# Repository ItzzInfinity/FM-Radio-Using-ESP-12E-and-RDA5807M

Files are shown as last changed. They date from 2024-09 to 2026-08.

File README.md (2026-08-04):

# FM Radio — RDA5807M 📻





## 📋 Overview

A small FM receiver built around the RDA5807M, driven over I2C by either an
ESP32-C3 SuperMini or an ESP-12E — the carrier board has a footprint for both
and the firmware picks its pin map from whichever core you compile for.

Audio leaves the board on a 2-pin header to a PAM8403 amplifier and a speaker;
a telescopic antenna solders to a plated mounting hole. Beyond the original
button-cycles-presets behaviour, the current firmware brings up Wi-Fi and serves
a web UI at `http://radio.local` for presets, volume, seek and manual tuning,
supports OTA reflashing, and optionally drives an SSD1306/SH1106 OLED.

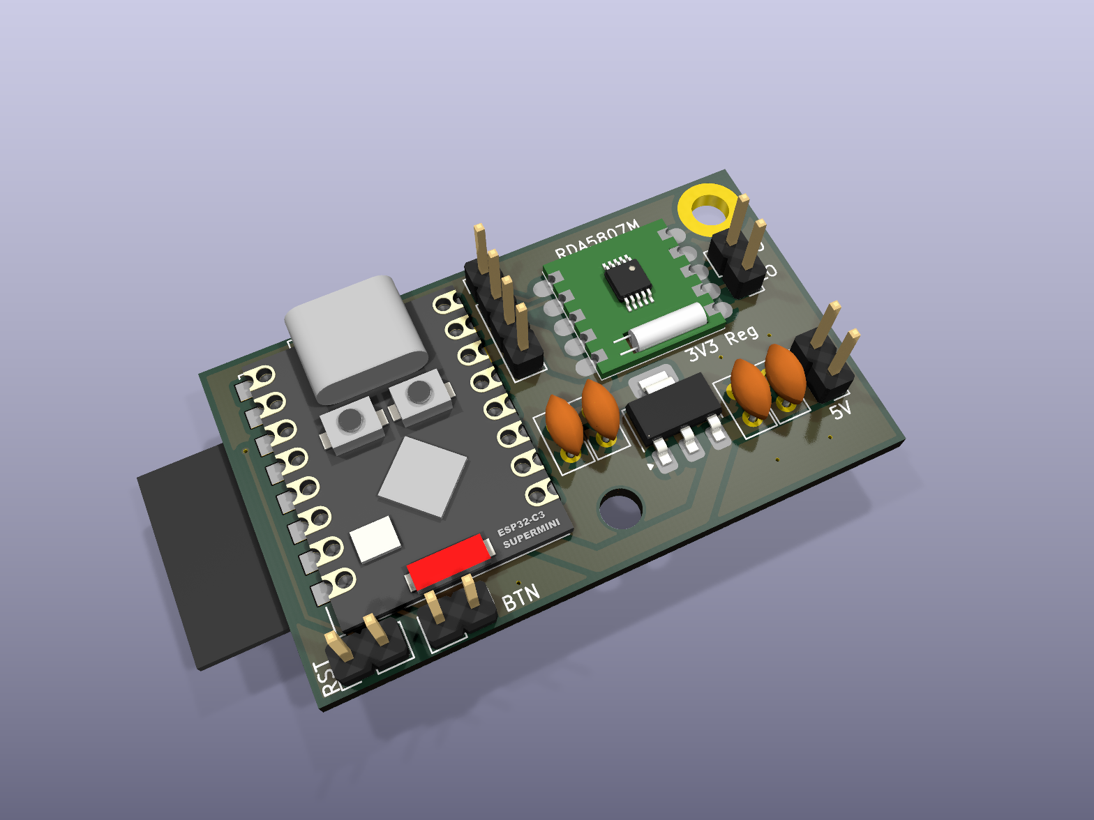
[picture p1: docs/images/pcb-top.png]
Assembled board, top view


## 🔧 Hardware

The board is a 2-layer 47.4 × 28.2 mm carrier. Reference designators differ
between the schematic and the PCB silkscreen — both are listed below.

| Sch | Silkscreen | Part | Notes |
|-----|---|---|---|
| U1 | `ESP32C3 SuperMini` | ESP32-C3 SuperMini | Top side, through-hole module |
| U2 | `ESP12E` | ESP-12E | **Bottom** side — the alternate MCU, see below |
| U3 | `U3` | RDA5807M module (RRD-102/120 style) | I2C 0x10 (sequential) / 0x11 (indexed) |
| U4 | `3V3 Reg` | AMS1117-3.3, SOT-223 | Only needed for the ESP-12E build |
| C1, C2 | `C1`, `C2` | Ceramic disc, 5 mm THT | AMS1117 input side |
| C3, C4 | `C3`, `C4` | Ceramic disc, 5 mm THT | AMS1117 output side |
| J2 | `GND` | 1×4 header | I2C breakout: SDA, SCL, 3V3, GND — for the OLED |
| J3 | `5V` | 1×2 header | 5 V supply in |
| J4 | `LO` | 1×2 header | Audio out: LOUT, ROUT → PAM8403 |
| SW1 | `RST` | 1×2 header | Reset, broken out for an external button |
| SW2 | `BTN` | 1×2 header | Preset button, broken out for an external button |
| H1 | `H1` | M3 mounting hole | |
| H2 | `H2` | M3 plated mounting hole | Carries the **ANT** net — solder the antenna here |

Notes on the BOM:

- **The capacitor values are not set in the schematic.** C1–C4 are drawn as
  generic `C` with 5 mm disc footprints. Fill them in before ordering; the
  AMS1117 datasheet wants at least 10 µF on the output for stability, which a
  disc ceramic will not give you.
- **SW1/SW2 are drawn as push buttons but laid out as 2-pin headers**, so the
  buttons live off-board. The tactile switches visible on the render are the
  SuperMini module's own boot/reset buttons, not board parts.
- H3 and H4 exist in the schematic but were never placed on the PCB.
- The PAM8403 amplifier, speaker, Li-Ion cell and TP4056 charger are off-board
  and not in this project.

### 📐 Schematic

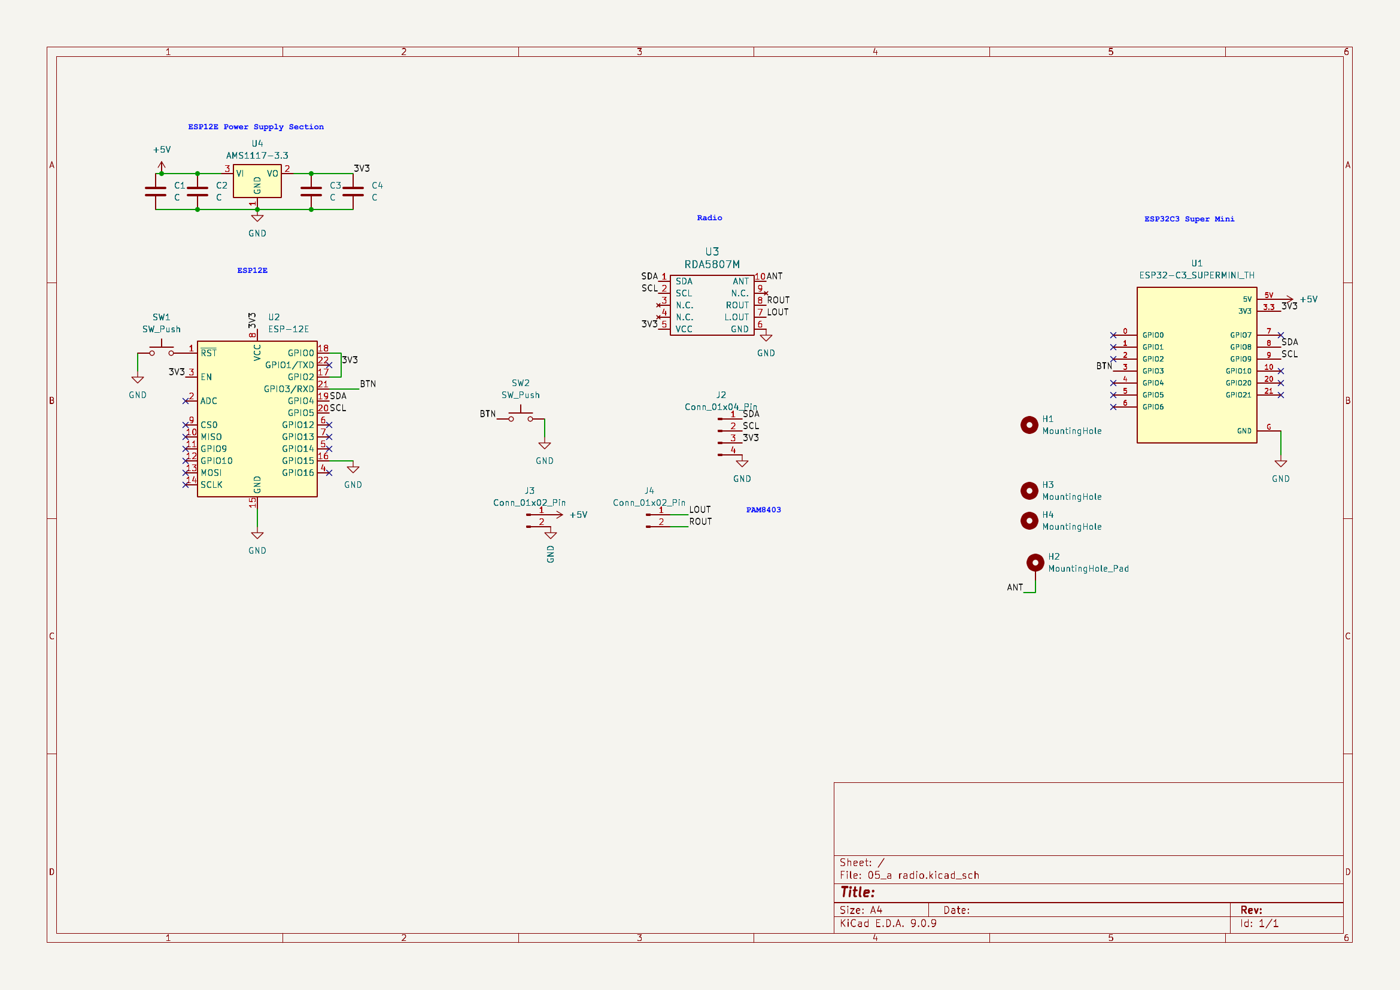
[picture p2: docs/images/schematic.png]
Schematic


*Click for the full-resolution PDF.*

### Board

| Top | Bottom |
|-----|---|
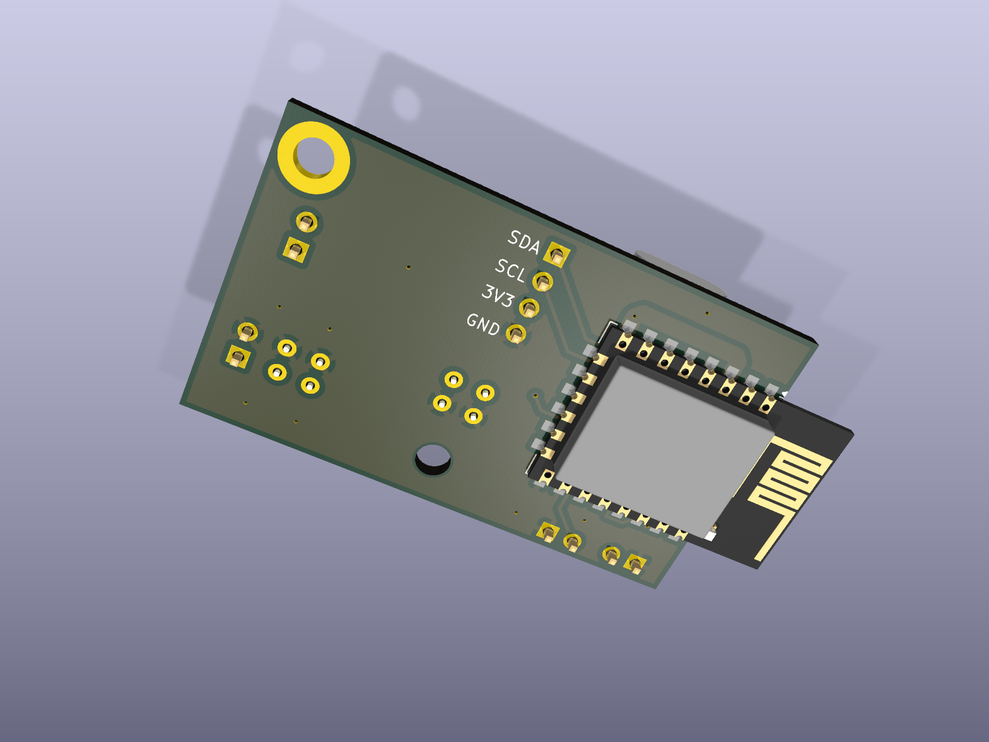
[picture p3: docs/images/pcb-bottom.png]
Bottom
| Top |  |

The KiCad 9 project is in [`hardware/`](hardware/). Both custom 3D models
(`ESP32-C3 supermini v5.step`, `RDA5807m-RRD-120.step`) are committed and
referenced through `${KIPRJMOD}`, so a fresh clone renders identically:

```bash
mkdir -p docs/images

kicad-cli sch export pdf -o docs/images/schematic.pdf "hardware/05_a radio.kicad_sch"
pdftoppm -r 200 -png -singlefile docs/images/schematic.pdf docs/images/schematic

kicad-cli pcb render --side top --quality high --perspective \
  --rotate '-25,0,25' --zoom 0.7 --width 1600 --height 1200 --floor \
  --background opaque -o docs/images/pcb-top.png "hardware/05_a radio.kicad_pcb"

kicad-cli pcb render --side bottom --quality high --perspective \
  --rotate '25,0,25' --zoom 0.52 --width 1600 --height 1200 --floor \
  --background opaque -o docs/images/pcb-bottom.png "hardware/05_a radio.kicad_pcb"
```

Gerbers are **not** committed — the exports under `hardware/Drill/` predated the
current layout, so they are gitignored. Regenerate with
`kicad-cli pcb export gerbers` before ordering.

## ⚡ Wiring

| Signal | ESP32-C3 (U1) | ESP-12E (U2) | Goes to |
|---|---|---|---|
| SDA | GPIO8 | GPIO4 (D2) | RDA5807M + J2 (OLED) |
| SCL | GPIO9 | GPIO5 (D1) | RDA5807M + J2 (OLED) |
| Button | GPIO3 | GPIO3 (RXD) | `BTN` header → GND |
| Reset | — | RST | `RST` header → GND |

These are the same values the firmware compiles in; the pin map lives in
section 2 of the sketch, keyed off `ESP8266` / `ARDUINO_ARCH_ESP32`.

### Three things that will bite you

**Populate one MCU, not both.** The ESP-12E sits on the bottom copper and the
SuperMini on the top, so nothing physically stops you fitting both — but they
share the I2C bus and the 3V3 rail. Pick one.

**Two regulators land on the same 3V3 net.** U1's `3.3` pin and the AMS1117's
output are the same node. With the SuperMini fitted, its onboard LDO already
powers the rail from the 5 V input, so leave `3V3 Reg` (U4) and C3/C4
unpopulated. The AMS1117 is only there for the ESP-12E build.

**GPIO8 and GPIO9 are ESP32-C3 strapping pins.** They are also the I2C bus here.
The chip samples both at reset — GPIO9 low selects download mode, and GPIO8 must
not be low — so the bus pull-ups have to be strong enough that nothing on the
bus drags either line down during boot. If the board only enumerates as a serial
port and never runs, this is the first thing to check.

On the ESP-12E, `pinMode()` on GPIO3 detaches it from UART0 RX: serial *output*
keeps working, serial *input* does not. That is inherited from the original
board and left as-is.

## 🧠 Design notes

**No radio library.** The RDA5807M driver is ~180 lines in section 4 of the
sketch. The chip is simple enough — 16-bit big-endian registers, two I2C
addresses (0x10 auto-incrementing, 0x11 indexed) — that a dependency buys
nothing and costs portability across the two cores.

**One sketch, two targets, no manual switch.** Everything board-specific is
behind `#if defined(ESP8266)` / `#elif defined(ARDUINO_ARCH_ESP32)`: pin map,
network headers, the web server type, and the persistence backend (EEPROM on
the ESP8266, `Preferences` on the ESP32). Selecting the board in the IDE is the
only choice you make.

**The OLED type is a runtime setting, not a compile-time one.** SSD1306 and
SH1106 are indistinguishable over I2C, so the firmware auto-detects that *an*
OLED is present and lets you switch the controller from the web page. Getting
the wrong module in a batch costs a click instead of a reflash. `OLED_ENABLED 0`
compiles the whole display path out.

**Audio survives an OTA update.** The RDA5807M only needs the MCU to change
station — it keeps playing on its own while flash is being rewritten. Both OTA
paths (the Arduino IDE network port and the browser upload at `/update`) are
guarded by `OTA_PASSWORD`, because otherwise anyone on the LAN can replace the
firmware. A failed transfer rolls back to the old image; only a successfully
written but broken sketch means opening the box.

**Credentials are gitignored.** This repo is public, so Wi-Fi and OTA passwords
live in `secrets.h`, which is not tracked. `secrets.h.example` is the template.

### HTTP API

The web page is served from flash at `/` and drives these endpoints:

| Endpoint | Purpose |
|---|---|
| `GET /api/status` | Current frequency, volume, stereo/RSSI, preset list |
| `GET /api/preset` | Select a preset slot |
| `GET /api/tune` | Tune to a frequency |
| `GET /api/volume` | Set volume 0–15 |
| `GET /api/seek` | Hardware seek up/down |
| `GET /api/preset/set` | Rewrite a preset slot (persisted) |
| `GET /api/oled` | Switch controller: `ssd1306` / `sh1106` / `none` |
| `GET`/`POST /update` | Browser firmware upload |

## 🔨 Build

```bash
cp Src/test_I2C_Radio/secrets.h.example Src/test_I2C_Radio/secrets.h
$EDITOR Src/test_I2C_Radio/secrets.h

# ESP32-C3 SuperMini
arduino-cli compile --fqbn esp32:esp32:esp32c3 Src/test_I2C_Radio

# ESP-12E
arduino-cli compile --fqbn esp8266:esp8266:nodemcuv2 Src/test_I2C_Radio
```

Requires the `Adafruit SSD1306`, `Adafruit SH110X`, `Adafruit GFX` and
`Adafruit BusIO` libraries unless you set `OLED_ENABLED 0`.

Verified with arduino-cli 1.5.1, esp32 core 3.3.8, esp8266 core 3.1.2:

| Target | Flash | RAM |
|---|---|-----|
| ESP32-C3 | 1,130,767 / 1,310,720 B (86%) | 44,252 / 327,680 B (13%) |
| ESP-12E | 340,684 / 1,048,576 B (32%) | 31,864 / 80,192 B (39%) |

Two figures worth watching: the ESP32-C3 build is at **86% of the default
1.3 MB app partition**, and the ESP-12E build sits at **93% of IRAM**
(61,551 / 65,536 B). Neither has much headroom left for new features.

## 🚀 First run

1. Copy `secrets.h.example` → `secrets.h` and fill in your Wi-Fi credentials
   and an OTA password.
2. Flash over USB the first time — OTA needs working firmware to update from.
3. Solder a telescopic antenna to the plated mounting hole H2.
4. Wire the `LO` header to a PAM8403 input and feed 5 V into the `5V` header.
   Take the amplifier's ground from that same header — `LO` carries only LOUT
   and ROUT, no ground of its own.
5. Browse to `http://radio.local`. If mDNS does not resolve, check the serial
   log for the DHCP address.
6. With no Wi-Fi at all the board still works: the `BTN` header cycles presets.

## 📟 Original prototype

The first version of this project was a hand-soldered perfboard build on an
ESP-12E with a fixed volume and 10 hard-coded stations — no Wi-Fi, no display,
one button. The carrier board above replaces it.

| Breadboard wiring | Perfboard build |
|---|---|
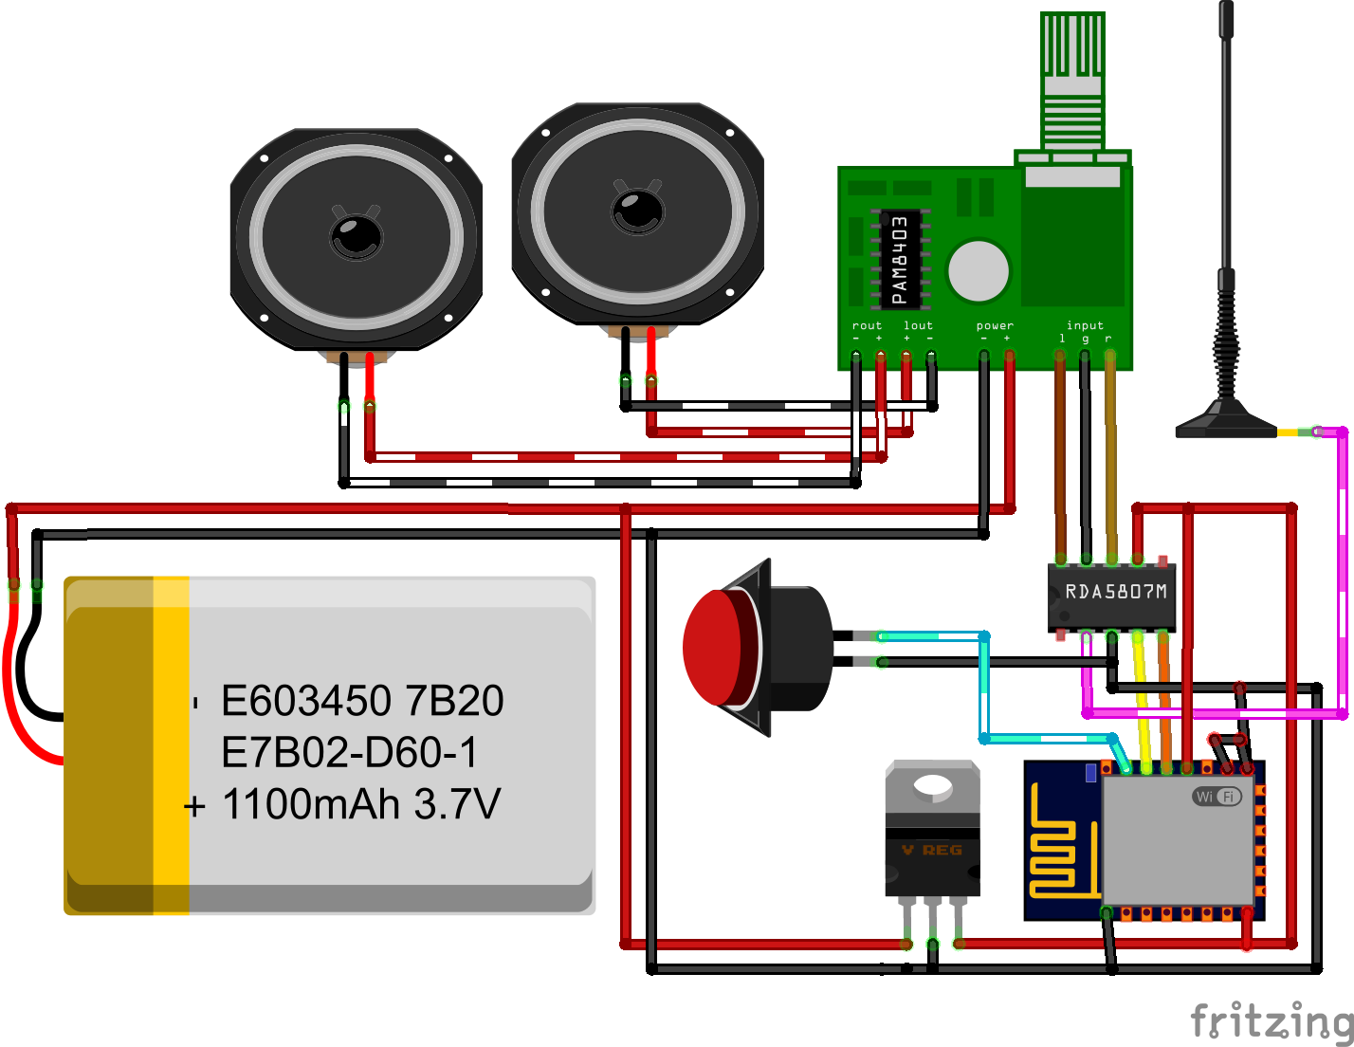
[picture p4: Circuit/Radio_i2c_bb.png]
Breadboard wiring
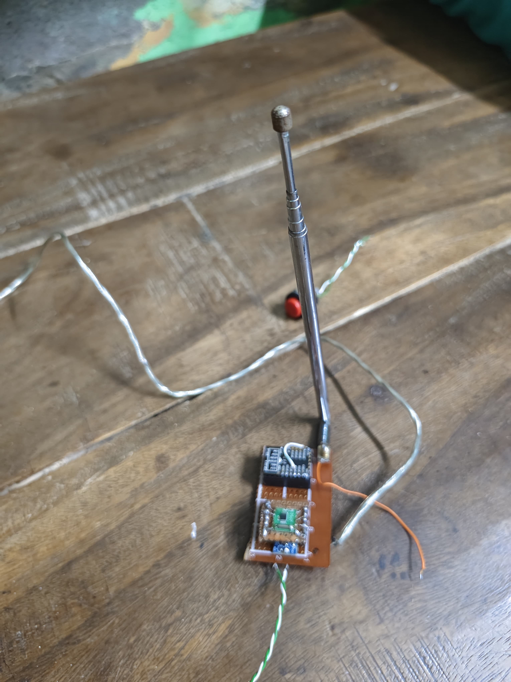
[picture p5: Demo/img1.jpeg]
Perfboard prototype
|  |  |

## 📜 License

MIT — see [LICENSE](LICENSE).

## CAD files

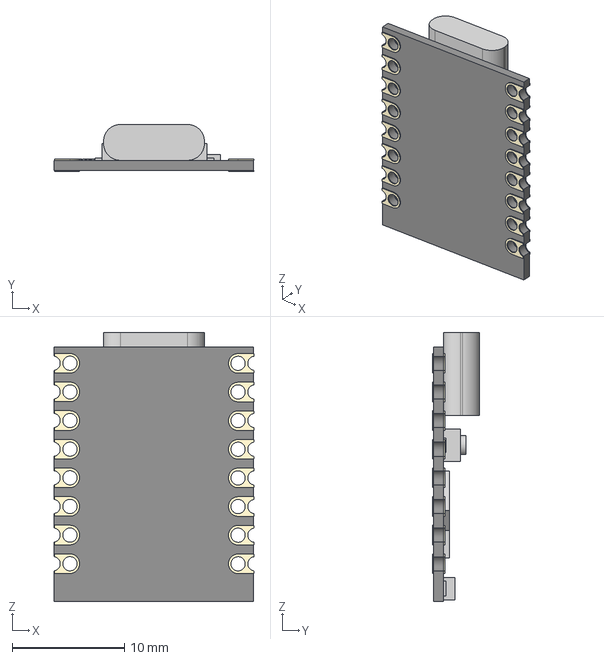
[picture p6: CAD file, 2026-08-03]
hardware/ESP32-C3 supermini v5.step
17.8 x 4.20 x 24.0 mm

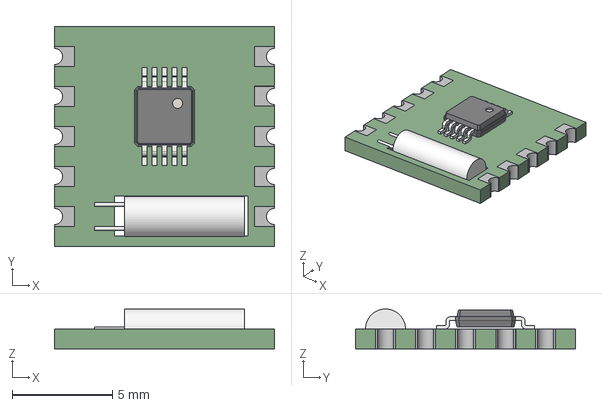
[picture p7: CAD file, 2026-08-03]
hardware/RDA5807m-RRD-120.step
11.0 x 11.0 x 2.00 mm

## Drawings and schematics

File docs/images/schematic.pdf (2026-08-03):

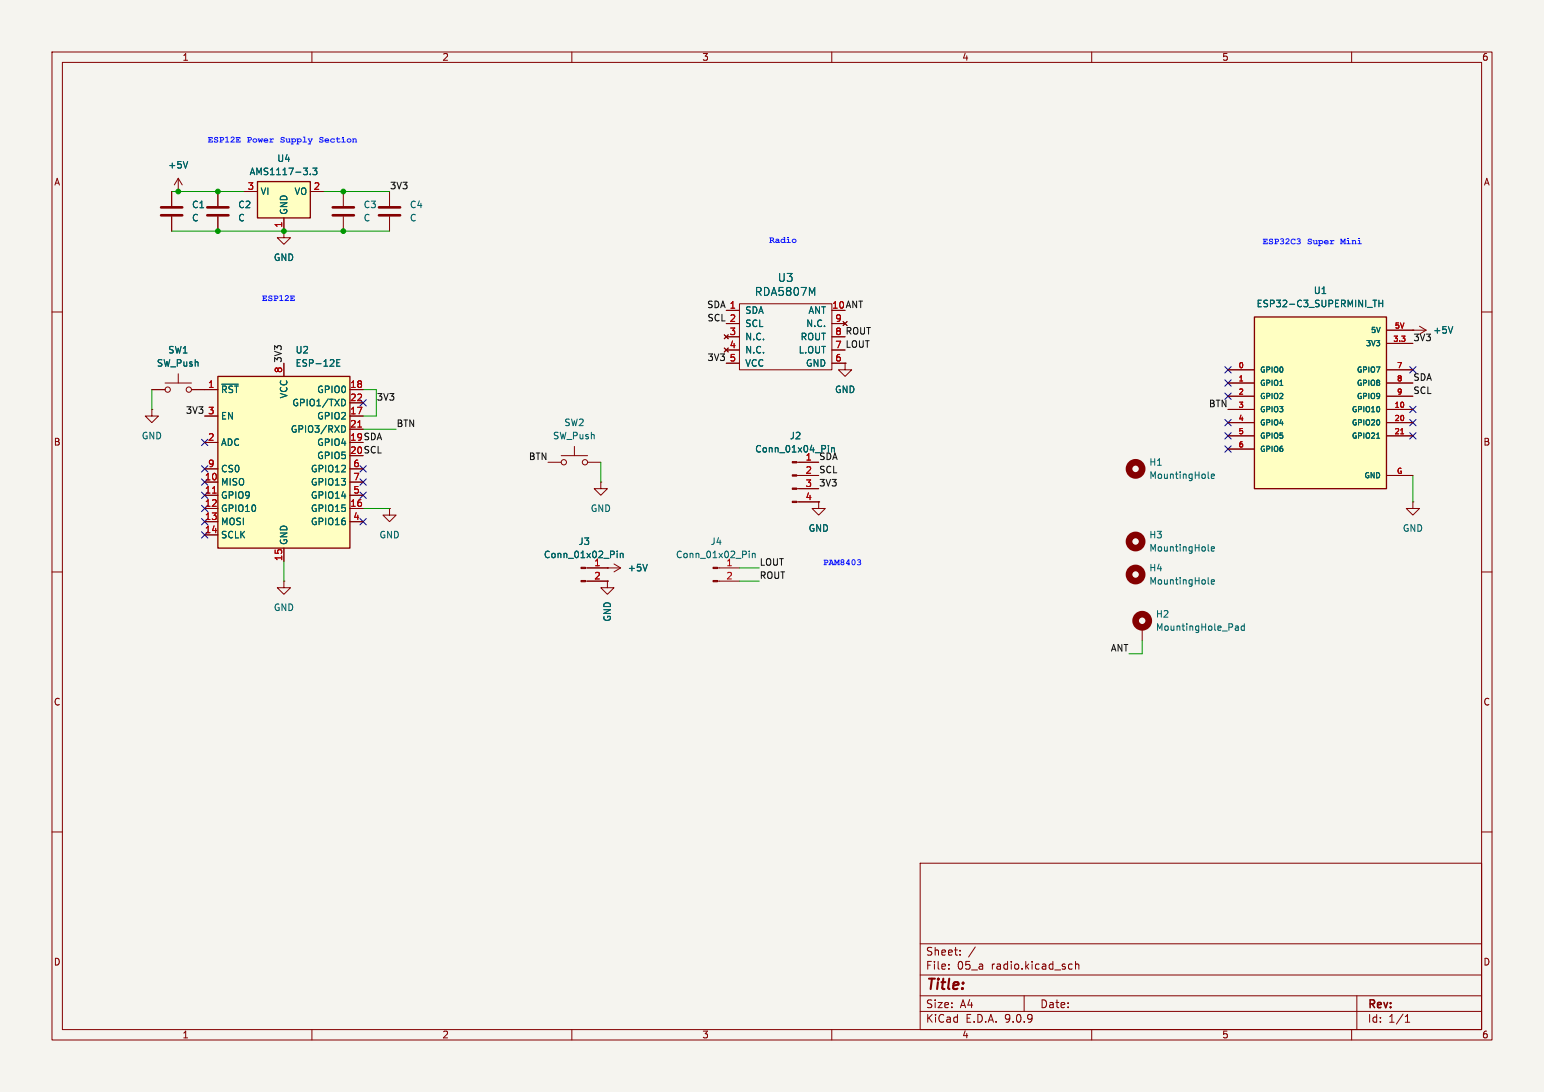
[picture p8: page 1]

8 GND 15 GPIO0 18 GPIO1/TXD 22 GPIO2 17 GPIO3/RXD 21 GPIO4 19 GPIO5 20 GPIO12 6 GPIO13 7 GPIO14 5 GPIO15 16 GPIO16 4 U2ESP-12E H4 MountingHole H3 MountingHole H2 MountingHole_Pad H1 MountingHole GND

Id: 1/1 Title: File: 05_a radio.kicad_sch Sheet: /

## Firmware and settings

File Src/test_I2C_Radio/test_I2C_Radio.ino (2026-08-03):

/*
 * ===========================================================================
 *  FM Radio  --  RDA5807M  --  ESP8266 (ESP-12E) / ESP32-C3
 * ===========================================================================
 *
 *  One sketch, two targets. Pick the board in the IDE (or with --fqbn) and
 *  flash -- the pin map and the platform APIs follow automatically, there is
 *  no second switch to keep in sync.
 *
 *  Features
 *    - Self-contained RDA5807M driver (no external radio library needed)
 *    - Web UI on http://radio.local : presets, volume, seek, manual tune,
 *      and editable preset slots
 *    - Station + volume + presets persist across power cycles
 *    - Optional SSD1306 / SH1106 OLED, auto-detected on the I2C bus and
 *      switchable from the web page without reflashing
 *    - Hardware button still cycles presets with no Wi-Fi at all
 *
 *  Wiring (unchanged from the original board)
 *    RDA5807M  SDA/SCL -> see PIN_SDA / PIN_SCL below, I2C addr 0x10 / 0x11
 *    OLED      SDA/SCL -> same bus, I2C addr 0x3C (or 0x3D)
 *    Button    -> PIN_BUTTON to GND (internal pull-up)
 *
 *  Build check:
 *    arduino-cli compile --fqbn esp8266:esp8266:nodemcuv2 <sketchdir>
 *    arduino-cli compile --fqbn esp32:esp32:esp32c3       <sketchdir>
 */

#include <Arduino.h>
#include <Wire.h>

// ===========================================================================
//  1. USER CONFIGURATION
// ===========================================================================

// --- Wi-Fi and OTA credentials ---------------------------------------------
// This repository is public on GitHub, so the credentials live in a separate
// gitignored file rather than in the sketch. Before the first build:
//
//   cp secrets.h.example secrets.h     # then edit secrets.h
//
// It defines WIFI_SSID, WIFI_PASSWORD, OTA_USERNAME and OTA_PASSWORD.
#include "secrets.h"

// Reachable as http://radio.local (and as the plain DHCP IP either way).
#define MDNS_HOSTNAME "radio"

// --- OTA (over-the-air firmware update) ------------------------------------
// The board lives in a sealed enclosure, so there are two independent ways to
// reflash it without opening the box. See section 8 for the details.
#define OTA_ENABLED 1

// OTA_PASSWORD guards BOTH update paths and OTA_USERNAME names the browser
// upload page's login; both come from secrets.h above.

// Shown on the web page so you can confirm an update actually landed.
#define FW_BUILD __DATE__ " " __TIME__

// --- Display ---------------------------------------------------------------
// OLED_ENABLED 0 compiles the display code out entirely: no Adafruit library
// is pulled in and the sketch is a pure headless radio.
#define OLED_ENABLED 1

// Default controller for a freshly-flashed board. The two chips are
// indistinguishable over I2C, so this is the starting guess -- if the module
// you fit shows garbage or is shifted a couple of pixels, switch it on the
// web page instead of reflashing. The choice is remembered in flash.
//   OLED_TYPE_SSD1306 | OLED_TYPE_SH1106 | OLED_TYPE_NONE
#define OLED_DEFAULT OLED_TYPE_SSD1306

// --- Radio -----------------------------------------------------------------
// 50 us de-emphasis is correct for India / Europe / most of the world.
// Set to 0 for the 75 us standard used in the Americas / South Korea.
#define FM_DEEMPHASIS_50US 1

// Soft mute pulls the audio down on very weak signals. Nice for seek, but it
// can make a marginal station breathe -- set to 0 if you prefer raw hiss.
#define FM_SOFTMUTE 1

// --- Presets ---------------------------------------------------------------
// Frequencies in 10 kHz units: 10400 == 104.00 MHz.
// These are the factory defaults; they can be renamed and re-tuned from the
// web page afterwards, and the edits are stored in flash.
#define PRESET_COUNT 10
static const uint16_t FACTORY_PRESETS[PRESET_COUNT] = {
  10620, 9270, 9350, 9430, 9830, 10130, 10260, 10400, 10480, 10640
};

// Volume 0..15 on a fresh board.
#define DEFAULT_VOLUME 13

// ===========================================================================
//  2. BOARD PIN MAP  +  PLATFORM SHIMS
// ===========================================================================

#if defined(ESP8266)
  #define BOARD_NAME "ESP8266 (ESP-12E)"
  constexpr int PIN_SDA    = 4;   // D2
  constexpr int PIN_SCL    = 5;   // D1
  // GPIO3 is UART0 RX. pinMode() below detaches it from the UART, so Serial
  // *output* on GPIO1 keeps working but Serial input does not. This matches
  // the original board, so the pin is left as-is.
  constexpr int PIN_BUTTON = 3;

  #include <ESP8266WiFi.h>
  #include <ESP8266WebServer.h>
  #include <ESP8266mDNS.h>
  #include <EEPROM.h>
  #include <WiFiUdp.h>          // OTA needs WiFiUDP::stopAll() before flashing
  typedef ESP8266WebServer WebServerClass;
  // "Update" (UpdaterClass) is pulled in by the core's Arduino.h.

#elif defined(ARDUINO_ARCH_ESP32)
  #define BOARD_NAME "ESP32-C3"
  constexpr int PIN_SDA    = 8;
  constexpr int PIN_SCL    = 9;
  constexpr int PIN_BUTTON = 3;

  #include <WiFi.h>
  #include <WebServer.h>
  #include <ESPmDNS.h>
  #include <Preferences.h>
  #include <Update.h>
  typedef WebServer WebServerClass;

#else
  #error "Unsupported board: select an ESP8266 (ESP-12E / NodeMCU) or an ESP32-C3."
#endif

#if OTA_ENABLED
  #include <ArduinoOTA.h>       // same header name on both cores
#endif

// ===========================================================================
//  3. SETTINGS  +  PERSISTENCE
// ===========================================================================

enum : uint8_t {
  OLED_TYPE_NONE    = 0,
  OLED_TYPE_SSD1306 = 1,
  OLED_TYPE_SH1106  = 2
};

#define PRESET_NAME_LEN 13          // 12 visible characters + NUL
#define SETTINGS_MAGIC  0x524Du     // 'RM'
#define SETTINGS_VER    1u
#define PRESET_MANUAL   0xFFu       // presetIdx value meaning "manually tuned"

struct Preset {
  uint16_t freq10k;
  char     name[PRESET_NAME_LEN];
};

struct Settings {
  uint16_t magic;
  uint16_t version;
  uint16_t freq10k;                 // last tuned frequency, 10 kHz units
  uint8_t  presetIdx;               // 0..9, or PRESET_MANUAL
  uint8_t  volume;                  // 0..15
  uint8_t  oledType;                // OLED_TYPE_*
  uint8_t  pad;
  Preset   presets[PRESET_COUNT];
  uint16_t crc;
};

static Settings cfg;
static bool          cfgDirty       = false;
static unsigned long cfgDirtySince  = 0;
static const unsigned long CFG_SAVE_DELAY_MS = 2000;   // debounce flash writes

#if defined(ARDUINO_ARCH_ESP32)
static Preferences prefs;
#endif

// "104.0" from 10400. Buffer must hold at least 8 bytes.
static void freqToStr(uint16_t f10k, char *out, size_t len) {
  snprintf(out, len, "%u.%u", (unsigned)(f10k / 100), (unsigned)((f10k / 10) % 10));
}

static uint16_t crc16(const uint8_t *data, size_t len) {
  uint16_t crc = 0xFFFF;
  for (size_t i = 0; i < len; i++) {
    crc ^= (uint16_t)data[i] << 8;
    for (uint8_t b = 0; b < 8; b++)
      crc = (crc & 0x8000) ? (uint16_t)((crc << 1) ^ 0x1021) : (uint16_t)(crc << 1);
  }
  return crc;
}

static uint16_t settingsCrc(const Settings &s) {
  return crc16((const uint8_t *)&s, sizeof(Settings) - sizeof(uint16_t));
}

static void settingsDefaults() {
  memset(&cfg, 0, sizeof(cfg));
  cfg.magic     = SETTINGS_MAGIC;
  cfg.version   = SETTINGS_VER;
  cfg.presetIdx = 0;
  cfg.freq10k   = FACTORY_PRESETS[0];
  cfg.volume    = DEFAULT_VOLUME;
  cfg.oledType  = OLED_DEFAULT;
  for (uint8_t i = 0; i < PRESET_COUNT; i++) {
    cfg.presets[i].freq10k = FACTORY_PRESETS[i];
    freqToStr(FACTORY_PRESETS[i], cfg.presets[i].name, PRESET_NAME_LEN);
  }
}

static void settingsLoad() {
  Settings tmp;
  bool ok = false;

#if defined(ESP8266)
  EEPROM.begin(sizeof(Settings) + 8);
  EEPROM.get(0, tmp);
  EEPROM.end();
  ok = true;
#else
  prefs.begin("radio", false);
  ok = (prefs.getBytes("cfg", &tmp, sizeof(tmp)) == sizeof(tmp));
  prefs.end();
#endif

  if (ok && tmp.magic == SETTINGS_MAGIC && tmp.version == SETTINGS_VER &&
      tmp.crc == settingsCrc(tmp)) {
    cfg = tmp;
    // Guard against a good CRC over out-of-range values.
    if (cfg.volume > 15) cfg.volume = DEFAULT_VOLUME;
    if (cfg.presetIdx >= PRESET_COUNT && cfg.presetIdx != PRESET_MANUAL) cfg.presetIdx = 0;
    if (cfg.freq10k < 8700 || cfg.freq10k > 10800) cfg.freq10k = FACTORY_PRESETS[0];
    if (cfg.oledType > OLED_TYPE_SH1106) cfg.oledType = OLED_DEFAULT;
    for (uint8_t i = 0; i < PRESET_COUNT; i++) {
      cfg.presets[i].name[PRESET_NAME_LEN - 1] = '\0';
      if (cfg.presets[i].freq10k < 8700 || cfg.presets[i].freq10k > 10800)
        cfg.presets[i].freq10k = FACTORY_PRESETS[i];
    }
    Serial.println(F("[cfg] restored from flash"));
  } else {
    settingsDefaults();
    Serial.println(F("[cfg] no valid settings, using factory defaults"));
  }
}

static void settingsSaveNow() {
  cfg.magic   = SETTINGS_MAGIC;
  cfg.version = SETTINGS_VER;
  cfg.crc     = settingsCrc(cfg);

#if defined(ESP8266)
  EEPROM.begin(sizeof(Settings) + 8);
  EEPROM.put(0, cfg);
  EEPROM.commit();
  EEPROM.end();
#else
  prefs.begin("radio", false);
  prefs.putBytes("cfg", &cfg, sizeof(cfg));
  prefs.end();
#endif

  cfgDirty = false;
  Serial.println(F("[cfg] saved"));
}

// Mark settings changed; the actual write happens once the user stops
// fiddling, so dragging the volume slider does not hammer the flash.
static void settingsTouch() {
  cfgDirty      = true;
  cfgDirtySince = millis();
}

static void settingsTick() {
  if (cfgDirty && millis() - cfgDirtySince >= CFG_SAVE_DELAY_MS) settingsSaveNow();
}

// ===========================================================================
//  4. RDA5807M DRIVER
// ===========================================================================
//
//  The chip answers on two I2C addresses:
//    0x10  sequential access -- writes start at register 0x02, reads at 0x0A,
//          both auto-incrementing
//    0x11  indexed access    -- write the register number, then 16 bits of data
//
//  Registers are 16 bit, big-endian on the wire.

#define RDA_ADDR_SEQ  0x10
#define RDA_ADDR_IDX  0x11

#define RDA_REG_CTRL  0x02
#define RDA_REG_CHAN  0x03
#define RDA_REG_R4    0x04
#define RDA_REG_VOL   0x05
#define RDA_REG_STAT  0x0A   // read-only: RDSR STC SF RDSS BLKE ST READCHAN
#define RDA_REG_RSSI  0x0B   // read-only: RSSI FM_TRUE FM_READY ...

// Register 0x02 bits
#define RDA_DHIZ       0x8000
#define RDA_DMUTE      0x4000
#define RDA_MONO       0x2000
#define RDA_BASS       0x1000
#define RDA_SEEKUP     0x0200
#define RDA_SEEK       0x0100
#define RDA_SKMODE     0x0080
#define RDA_RDS_EN     0x0008
#define RDA_NEW_METHOD 0x0004
#define RDA_SOFT_RESET 0x0002
#define RDA_ENABLE     0x0001

// Register 0x03 bits
#define RDA_TUNE       0x0010

// Register 0x04 bits
#define RDA_DE_50US    0x0800
#define RDA_SOFTMUTE   0x0200

// Register 0x0A / 0x0B bits
#define RDA_STC        0x4000
#define RDA_SF         0x2000
#define RDA_ST         0x0400
#define RDA_FM_TRUE    0x0100

// Band 87..108 MHz, 100 kHz spacing -> channel n is 87.00 MHz + n * 100 kHz.
#define FM_BAND_LOW10K   8700
#define FM_BAND_HIGH10K  10800
#define FM_STEP10K       10

class RDA5807M {
public:
  bool begin() {
    Wire.beginTransmission(RDA_ADDR_IDX);
    _present = (Wire.endTransmission() == 0);
    if (!_present) return false;

    writeReg(RDA_REG_CTRL, RDA_SOFT_RESET);
    delay(50);

    _ctrl = RDA_DHIZ | RDA_DMUTE | RDA_BASS | RDA_NEW_METHOD | RDA_ENABLE;
    writeReg(RDA_REG_CTRL, _ctrl);
    delay(50);

    uint16_t r4 = 0;
#if FM_DEEMPHASIS_50US
    r4 |= RDA_DE_50US;
#endif
#if FM_SOFTMUTE
    r4 |= RDA_SOFTMUTE;
#endif
    writeReg(RDA_REG_R4, r4);

    // 0x8880: INT_MODE, seek threshold 8, LNA on LNAP -- the datasheet's
    // recommended defaults, with the volume in the low nibble.
    _vol = DEFAULT_VOLUME;
    writeReg(RDA_REG_VOL, 0x8880 | _vol);
    return true;
  }

  bool present() const { return _present; }

  void setVolume(uint8_t v) {
    if (v > 15) v = 15;
    _vol = v;
    if (_present) writeReg(RDA_REG_VOL, 0x8880 | _vol);
  }
  uint8_t volume() const { return _vol; }

  // f10k is in 10 kHz units (10400 == 104.00 MHz).
  void setFrequency(uint16_t f10k) {
    _freq = clampFreq(f10k);
    if (!_present) return;
    uint16_t chan = (uint16_t)((_freq - FM_BAND_LOW10K) / FM_STEP10K);
    writeReg(RDA_REG_CHAN, (uint16_t)(chan << 6) | RDA_TUNE);   // band 00, space 00
    waitForSTC(150);
  }
  uint16_t frequency() const { return _freq; }

  // Hardware seek. Returns where it actually landed.
  uint16_t seek(bool up) {
    if (!_present) return _freq;
    uint16_t c = _ctrl | RDA_SEEK | RDA_SKMODE;     // SKMODE: stop at band edge
    if (up) c |= RDA_SEEKUP; else c &= (uint16_t)~RDA_SEEKUP;
    writeReg(RDA_REG_CTRL, c);
    waitForSTC(3000);                                // a full sweep can be slow
    writeReg(RDA_REG_CTRL, _ctrl);                   // clear the seek request
    readStatus(true);
    return _freq;
  }

  // Refreshes the cached RSSI / stereo / tuned flags, at most every 500 ms
  // unless forced.
  void readStatus(bool force = false) {
    if (!_present) return;
    unsigned long now = millis();
    if (!force && now - _lastStatus < 500) return;
    _lastStatus = now;

    Wire.requestFrom((uint8_t)RDA_ADDR_SEQ, (uint8_t)4);
    if (Wire.available() < 4) return;
    uint16_t rA = (uint16_t)(Wire.read() << 8); rA |= (uint8_t)Wire.read();
    uint16_t rB = (uint16_t)(Wire.read() << 8); rB |= (uint8_t)Wire.read();

    _stereo = (rA & RDA_ST) != 0;
    _tuned  = (rB & RDA_FM_TRUE) != 0;
    _rssi   = (uint8_t)((rB >> 9) & 0x7F);

    uint16_t chan = rA & 0x03FF;
    uint16_t f    = (uint16_t)(FM_BAND_LOW10K + chan * FM_STEP10K);
    if (f >= FM_BAND_LOW10K && f <= FM_BAND_HIGH10K) _freq = f;
  }

  uint8_t rssi()   const { return _rssi; }    // 0..127
  bool    stereo() const { return _stereo; }
  bool    tuned()  const { return _tuned; }

  static uint16_t clampFreq(uint16_t f10k) {
    if (f10k < FM_BAND_LOW10K)  f10k = FM_BAND_LOW10K;
    if (f10k > FM_BAND_HIGH10K) f10k = FM_BAND_HIGH10K;
    // Snap to the 100 kHz channel grid.
    return (uint16_t)(FM_BAND_LOW10K +
                      ((f10k - FM_BAND_LOW10K + FM_STEP10K / 2) / FM_STEP10K) * FM_STEP10K);
  }

private:
  void writeReg(uint8_t reg, uint16_t val) {
    Wire.beginTransmission(RDA_ADDR_IDX);
    Wire.write(reg);
    Wire.write((uint8_t)(val >> 8));
    Wire.write((uint8_t)(val & 0xFF));
    Wire.endTransmission();
  }

  uint16_t readReg0A() {
    Wire.requestFrom((uint8_t)RDA_ADDR_SEQ, (uint8_t)2);
    if (Wire.available() < 2) return 0;
    uint16_t v = (uint16_t)(Wire.read() << 8);
    return v | (uint8_t)Wire.read();
  }

  // Poll the seek/tune-complete flag. Bounded so a dead chip cannot wedge the
  // sketch, and yields so Wi-Fi keeps being serviced.
  void waitForSTC(unsigned long timeoutMs) {
    unsigned long start = millis();
    while (millis() - start < timeoutMs) {
      if (readReg0A() & RDA_STC) break;
      delay(5);
    }
  }

  bool          _present    = false;
  uint16_t      _ctrl       = 0;
  uint16_t      _freq       = FM_BAND_LOW10K;
  uint8_t       _vol        = DEFAULT_VOLUME;
  uint8_t       _rssi       = 0;
  bool          _stereo     = false;
  bool          _tuned      = false;
  unsigned long _lastStatus = 0;
};

static RDA5807M radio;

// ===========================================================================
//  5. OPTIONAL OLED
// ===========================================================================
//
//  Both drivers are declared but only the selected one gets begin() called,
//  so only one framebuffer is ever allocated. Everything except clearDisplay()
//  and display() goes through the shared Adafruit_GFX base, so the drawing
//  code below is written once.

#if OLED_ENABLED
  #include <Adafruit_GFX.h>
  #include <Adafruit_SSD1306.h>
  #include <Adafruit_SH110X.h>

  #define OLED_W 128
  #define OLED_H 64
  #define OLED_ON 1                 // SSD1306_WHITE and SH110X_WHITE are both 1

  static Adafruit_SSD1306 oledSSD(OLED_W, OLED_H, &Wire, -1);
  static Adafruit_SH1106G oledSH(OLED_W, OLED_H, &Wire, -1);

  static Adafruit_GFX *gfx        = nullptr;
  static bool          oledActive = false;
  static uint8_t       oledAddr   = 0;
#endif

// Probes both usual OLED addresses. 0 == nothing there.
static uint8_t oledProbe() {
  const uint8_t addrs[2] = { 0x3C, 0x3D };
  for (uint8_t i = 0; i < 2; i++) {
    Wire.beginTransmission(addrs[i]);
    if (Wire.endTransmission() == 0) return addrs[i];
  }
  return 0;
}

// Brings the display up for the given controller type. Safe to call again at
// runtime when the user switches controller from the web page.
static void oledBegin(uint8_t type) {
#if OLED_ENABLED
  oledActive = false;
  gfx        = nullptr;

  if (type == OLED_TYPE_NONE) {
    Serial.println(F("[oled] disabled"));
    return;
  }

  oledAddr = oledProbe();
  if (!oledAddr) {
    Serial.println(F("[oled] none found on the bus (that is fine, it is optional)"));
    return;
  }

  if (type == OLED_TYPE_SSD1306) {
    // reset=false (no reset pin), periphBegin=false (Wire is already up).
    if (oledSSD.begin(SSD1306_SWITCHCAPVCC, oledAddr, false, false)) {
      gfx = &oledSSD;
      oledActive = true;
    }
  } else {
    if (oledSH.begin(oledAddr, false)) {
      gfx = &oledSH;
      oledActive = true;
    }
  }

  if (oledActive) {
    gfx->setTextWrap(false);
    Serial.printf("[oled] %s at 0x%02X\n",
                  (type == OLED_TYPE_SSD1306) ? "SSD1306" : "SH1106", oledAddr);
  } else {
    Serial.println(F("[oled] found a device but init failed"));
  }
#else
  (void)type;
#endif
}

static inline void oledClear() {
#if OLED_ENABLED
  if (!oledActive) return;
  if (gfx == (Adafruit_GFX *)&oledSSD) oledSSD.clearDisplay(); else oledSH.clearDisplay();
#endif
}

static inline void oledShow() {
#if OLED_ENABLED
  if (!oledActive) return;
  if (gfx == (Adafruit_GFX *)&oledSSD) oledSSD.display(); else oledSH.display();
#endif
}

// Forward declarations used by the display code.
static const char *currentStationName();
static bool        wifiUp();

static void oledRender() {
#if OLED_ENABLED
  if (!oledActive) return;

  char fbuf[10];
  freqToStr(cfg.freq10k, fbuf, sizeof(fbuf));

  oledClear();
  gfx->setTextColor(OLED_ON);

  // Top line: station name, plus a stereo marker on the right.
  gfx->setTextSize(1);
  gfx->setCursor(0, 0);
  gfx->print(currentStationName());
  if (radio.stereo()) { gfx->setCursor(110, 0); gfx->print(F("ST")); }

  // Frequency, large.
  gfx->setTextSize(3);
  gfx->setCursor(0, 12);
  gfx->print(fbuf);
  gfx->setTextSize(1);
  gfx->setCursor(94, 29);
  gfx->print(F("MHz"));

  // Signal strength, five bars in the top right under the ST marker.
  uint8_t bars = (uint8_t)((radio.rssi() * 5) / 64);
  if (bars > 5) bars = 5;
  for (uint8_t i = 0; i < 5; i++) {
    int16_t h = (int16_t)(2 + i * 2);
    int16_t x = (int16_t)(96 + i * 3);
    if (i < bars) gfx->fillRect(x, 10 - h, 2, h, OLED_ON);
    else          gfx->drawRect(x, 10 - h, 2, h, OLED_ON);
  }

  // Volume bar.
  gfx->setCursor(0, 40);
  gfx->print(F("VOL"));
  gfx->drawRect(24, 40, 104, 7, OLED_ON);
  if (radio.volume() > 0)
    gfx->fillRect(26, 42, (int16_t)((100 * radio.volume()) / 15), 3, OLED_ON);

  // Bottom line: how to reach it.
  gfx->setCursor(0, 56);
  if (!radio.present())    gfx->print(F("RDA5807M not found"));
  else if (wifiUp())       gfx->print(WiFi.localIP().toString());
  else                     gfx->print(F("Wi-Fi: connecting..."));

  oledShow();
#endif
}

// ===========================================================================
//  6. RADIO STATE
// ===========================================================================

static const char *currentStationName() {
  if (cfg.presetIdx < PRESET_COUNT) return cfg.presets[cfg.presetIdx].name;
  return "Manual";
}

// Applies a frequency and works out whether it happens to match a preset.
static void applyFrequency(uint16_t f10k, uint8_t presetIdx) {
  cfg.freq10k = RDA5807M::clampFreq(f10k);
  radio.setFrequency(cfg.freq10k);

  if (presetIdx < PRESET_COUNT) {
    cfg.presetIdx = presetIdx;
  } else {
    cfg.presetIdx = PRESET_MANUAL;
    for (uint8_t i = 0; i < PRESET_COUNT; i++)
      if (cfg.presets[i].freq10k == cfg.freq10k) { cfg.presetIdx = i; break; }
  }

  char fbuf[10];
  freqToStr(cfg.freq10k, fbuf, sizeof(fbuf));
  Serial.printf("[radio] %s MHz  (%s)\n", fbuf, currentStationName());

  radio.readStatus(true);
  settingsTouch();
  oledRender();
}

static void applyPreset(uint8_t i) {
  if (i >= PRESET_COUNT) return;
  applyFrequency(cfg.presets[i].freq10k, i);
}

static void applyVolume(uint8_t v) {
  if (v > 15) v = 15;
  cfg.volume = v;
  radio.setVolume(v);
  settingsTouch();
  oledRender();
}
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
void loop() {
  server.handleClient();
  otaTick();
#if defined(ESP8266)
  if (mdnsStarted) MDNS.update();
#endif

  // While firmware is being written, keep off the I2C bus and out of the
  // settings flash area -- the update owns the chip until it reboots.
  if (otaActive) {
    // A browser tab closed mid-upload never fires UPLOAD_FILE_ABORTED, so
    // without this the box would need a power cycle to become usable again.
    if (millis() - otaLastSeen > 30000) {
      otaActive = false;
      Serial.println(F("[ota] stalled, giving up and resuming normal operation"));
      oledRender();
    }
    return;
  }

  networkTick();
  buttonTick();
  settingsTick();

  radio.readStatus();                       // rate-limited internally

  static unsigned long lastDraw = 0;
  if (millis() - lastDraw >= 1000) {        // refresh RSSI / stereo on the OLED
    lastDraw = millis();
    oledRender();
  }
}
                                                                                 /// End.

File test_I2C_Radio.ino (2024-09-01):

///
/// \file  TestRDA5807M.ino
/// \brief An Arduino sketch to operate a SI4705 chip based radio using the Radio library.
///
/// \author Matthias Hertel, http://www.mathertel.de
/// \copyright Copyright (c) 2014 by Matthias Hertel.\n
/// This work is licensed under a BSD style license. See http://www.mathertel.de/License.aspx
///
/// \details
/// This sketch implements a "as simple as possible" radio without any possibility to modify the settings after initializing the chip.\n
/// The radio chip is initialized and setup to a fixed band and frequency. These settings can be changed by modifying the
/// FIX_BAND and FIX_STATION definitions.
///
/// Open the Serial console with 57600 baud to see the current radio information.
///
/// Wiring
/// ------
/// The RDA5807M board/chip has to be connected by using the following connections:
///
/// | Signal       | Arduino UNO | ESP8266 | ESP32  | Radio chip signal |
/// | ------------ | ------------| ------- | ------ | ----------------- |
/// | VCC (red)    | 3.3V        | 3v3     | 3v3    | VCC               |
/// | GND (black)  | GND         | GND     | GND    | GND               |
/// | SCL (yellow) | A5 / SCL    | D1      | 22     | SCLK              |
/// | SDA (blue)   | A4 / SDA    | D2      | 21     | SDIO              |
///
/// The locations of the signals on the RDA5807M side depend on the board you use.
/// More documentation is available at http://www.mathertel.de/Arduino
/// Source Code is available on https://github.com/mathertel/Radio
///
/// ChangeLog:
/// ----------
/// * 05.12.2014 created.
/// * 19.05.2015 extended.

#include <Arduino.h>
#include <Wire.h>

#include <radio.h>
#include <RDA5807M.h>

// ----- Fixed settings here. -----
#define FIX_BAND RADIO_BAND_FM                                                                                     ///< The band that will be tuned by this sketch is FM.
#define FIX_STATION 10400                                                                                          ///< The station that will be tuned by this sketch is 89.30 MHz.
#define FIX_VOLUME 13                                                                                              ///< The volume that will be set by this sketch is level 4.
const int buttonPin = 3;                                                                                           /// GPIO pin connected to the input button
RDA5807M radio;                                                                                                    /// Create an instance of Class for RDA5807M Chip
int count = 0;                                                                                                     /// Counter variable

unsigned long previousMillis = 0;                                                                                  /// Variable to store the previous time
const long interval = 3000;                                                                                        /// Interval (in milliseconds) for the delay




int radio_station[10]={10620,9270,9350,9430,9830,10130,10260,10400,10480,10640}; 
                                                                                                                   /// Setup a FM only radio configuration
                                                                                                                   /// with some debugging on the Serial port
void setup() {
                                                                                                                   /// open the Serial port
  Serial.begin(115200);
  Wire.begin(); //comment in case of esp01 @infinity
//  Wire.begin(2,0); //uncomment in case of esp01 @infinity
  pinMode(buttonPin, INPUT_PULLUP);  
                                                                                                                   /// Set button pin as input with pull-up resistor
  Serial.println("RDA5807M Radio...");
  delay(200);

                                                                                                                   /// Enable information to the Serial port
  radio.debugEnable(true);
  radio._wireDebug(false);

                                                                                                                   /// Set FM Options for Europe
  //radio.setup(RADIO_FMSPACING, RADIO_FMSPACING_100);   // for EUROPE
  //radio.setup(RADIO_DEEMPHASIS, RADIO_DEEMPHASIS_50);  // for EUROPE

                                                                                                                   /// Initialize the Radio
  if (!radio.initWire(Wire)) {
  Serial.println("no radio chip found.");
  delay(4000);
//  ESP.restart();
  };
                                                                  Serial.println(count);
                                                                  Serial.println(radio_station[count]);
  // Set all radio setting to the fixed values.
  radio.setBandFrequency(FIX_BAND, radio_station[count]);
  station_call_function();
  radio.setVolume(FIX_VOLUME);
  radio.setMono(false);
  radio.setMute(false);
}                                 /// setup


                                  /// show the current chip data every 3 seconds.
void loop() { 
  unsigned long currentMillis = millis();
  if (currentMillis - previousMillis >= interval) {                                                               /// Check if the interval has elapsed
  
  station_call_function();  
  previousMillis = currentMillis;                                                                                 /// Update the previous time for the next interval
  }
  if (digitalRead(buttonPin) == LOW) {                                                                            /// Check if button is pressed (LOW state due to pull-up resistor)
  count++;                                                                                                        /// Increment count
  if (count > 10) {                                                                                               /// Check if count is greater than 10
  count = 0;                                                                                                      /// Reset count to 0
  radio.setBandFrequency(FIX_BAND, radio_station[count]);
  }  
  radio.setBandFrequency(FIX_BAND, radio_station[count]);
  
  delay(1500);                                                                                                    /// Delay for readability (adjust as needed)
      
  }

}                    

int station_call_function(){
  char s[12];
  radio.formatFrequency(s, sizeof(s));
  Serial.print("Station:");
  Serial.println(s);

  Serial.print("Radio:");
  radio.debugRadioInfo();

  Serial.print("Audio:");
  radio.debugAudioInfo();
  return 0;
}

                                                                                                                /// End.
